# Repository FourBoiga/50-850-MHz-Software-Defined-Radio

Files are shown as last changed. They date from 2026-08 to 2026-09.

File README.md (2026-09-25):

# Wideband SDR (50–850 MHz)

## Overview

This project is a custom software-defined radio (SDR) designed to receive signals from approximately **50 MHz to 850 MHz**. The goal is to build a modular, low-cost SDR while learning RF engineering, analog design, FPGA development, and digital signal processing from the ground up.

Unlike many hobby SDRs that rely heavily on highly integrated tuner/transceiver ICs, this design uses discrete RF building blocks for much of the signal chain, including filtering, switching, amplification, mixing, local oscillator generation, and quadrature I/Q conversion.



---

## Goals

* Receive signals from approximately 50 MHz to 850 MHz
* Modular RF front-end
* Good dynamic range
* Low noise figure
* Quadrature I/Q output
* FPGA-based digital signal processing
* USB interface to a host PC
* Eventually interface with SDR software such as SDR++
* Learn professional RF and DSP design techniques

---

## Current Architecture

The signal starts at the antenna and passes through the RF protection and switched bandpass filter bank before being amplified by the LNA. From there it goes through the quadrature receiver and intermediate-frequency conversion stages, producing differential I/Q signals for the ADC. The ADC sends the digitized samples to the FPGA, where the DSP will be performed before the data is eventually sent to the host PC over USB.

---

The receiver uses multiple local oscillator paths generated from PLL frequency synthesizers referenced to a stable TCXO.

---

## Specifications

| Parameter | Specification |
| --- | ---: |
| Frequency Range | ~50–850 MHz |
| Architecture | Superheterodyne / Quadrature I/Q |
| Target IF Bandwidth | ~1 MHz |
| ADC | LTC2323-12 |
| ADC Resolution | 12-bit |
| ADC Sample Rate | 5 MSPS/channel |
| ADC Interface | SPI |
| FPGA | Sipeed Tang Nano 20K |
| Controller | STM32 Nucleo |
| Host Interface | USB |
| Output | Digital I/Q samples |

These are design targets and specifications; final RF performance will be determined through hardware testing and characterization.

---

## RF Front End

The RF front end consists of:

* RF input protection
* Switched bandpass filter bank
* RF switching
* Low-noise amplifier
* Quadrature receiver/mixer
* Intermediate-frequency conversion
* Local oscillator generation
* PLL frequency synthesizers
* TCXO reference

### Filter Architecture

The original design included additional filtering after the LNA. After reviewing the local RF environment and considering the additional simulation and design time required, the post-LNA filters were removed from the architecture.

The remaining pre-LNA filter bank provides the primary out-of-band filtering before amplification.

---

## Local Oscillator

The local oscillator system uses:

* Stable TCXO reference
* PLL frequency synthesizers
* LO generation for the receiver mixer
* LO generation for the IF mixer

The LO circuitry and synthesizers have been fully integrated into the PCB design.

---

## I/Q Receiver

The receiver produces differential I/Q signals which are digitized by the LTC2323-12 ADC.

During PCB design, the polarity of the Q differential pair was found to be opposite to the polarity expected by the ADC. Rather than rerouting the completed RF section, the differential inputs are intentionally swapped.

This produces a 180° phase inversion of the Q component, which will be corrected digitally in the FPGA by negating the Q samples.

---

## ADC

The SDR uses an **LTC2323-12** dual-channel 12-bit SAR ADC.

The planned configuration uses:

* 12-bit resolution
* 5 MSPS per channel
* Differential I/Q inputs
* SPI interface
* Up to 105 MHz SPI clock

The ADC provides the interface between the analog I/Q receiver and the FPGA's digital signal-processing chain.

---

## FPGA and DSP

The next major development phase is the FPGA firmware and digital signal processing.

The FPGA will initially implement a minimal processing chain capable of receiving and processing the raw I/Q samples from the ADC.

Planned processing includes:

```text
ADC I/Q Samples
       │
       ▼
Digital Filtering
       │
       ▼
Frequency Translation
       │
       ▼
Decimation
       │
       ▼
Sample Formatting
       │
       ▼
USB / Host PC
```

The FPGA development will be done using the **Sipeed Tang Nano 20K**.

The initial goal is not to immediately implement complete SDR++ compatibility. The first fallback target is simply to get raw or minimally processed I/Q samples from the FPGA to a computer.

A simple Python-based host program can then perform FFT processing and display the received spectrum. This provides a straightforward way to verify the complete RF → ADC → FPGA → PC signal path before implementing a more complete SDR software interface.

---

## PCB

The PCB design is now complete and is undergoing a final review before manufacturing.

Completed PCB work includes:

* RF protection
* Bandpass filter bank
* RF switching
* LNA
* Receiver/mixer circuitry
* Local oscillator circuitry
* PLL synthesizers
* I/Q differential routing
* ADC interface
* FPGA interface
* STM32 controller interface
* USB-C circuitry
* Debug SMA connector
* 50 Ω test line
* Test points
* Debug interfaces

The next steps are to perform the final PCB review, finalize the BOM, and submit the project for manufacturing/funding.

---

## Software

### FPGA

Planned FPGA functionality includes:

* LTC2323-12 SPI interface
* I/Q sample capture
* Q polarity correction
* Digital filtering
* Digital frequency translation
* Decimation
* I/Q data formatting
* USB data streaming

### Host PC

The initial host software will likely be a simple Python-based development tool capable of:

* Receiving I/Q samples
* Converting ADC samples into complex I/Q data
* Performing FFTs
* Displaying frequency spectra
* Visualizing received signals

The long-term goal is compatibility with existing SDR software such as SDR++.

---

## Major Engineering Challenges

* Wideband RF filter design
* RF PCB layout
* Maintaining controlled RF impedance
* Mixer integration
* Local oscillator synthesis
* LO phase noise
* Dynamic range
* Noise figure
* I/Q signal integrity
* ADC interfacing
* High-speed SPI
* FPGA DSP implementation
* Fixed-point digital signal processing
* Host-side I/Q streaming
* SDR software integration

One of the primary goals of the project is to understand and implement these individual systems rather than relying on a highly integrated SDR transceiver to hide their operation.

---

## Long-Term Goals

This project is intended to serve as a platform for experimentation and learning in:

* RF Engineering
* Analog Electronics
* RF PCB Design
* FPGA Development
* Digital Signal Processing
* Software-Defined Radio
* Communication Systems

Future revisions may improve filtering, dynamic range, instantaneous bandwidth, frequency coverage, DSP capabilities, and host software.

---

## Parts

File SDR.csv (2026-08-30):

Reference | Qty | Value | DNP | Exclude from BOM | Exclude from Board | Footprint | Datasheet | Description
C1,C2,C10,C11 | 4 | 100pF |  |  |  | Capacitor_SMD:C_0402_1005Metric |  | C0G
C3,C9,C58,C59,C60,C61,C62 | 7 | 10nF |  |  |  | Capacitor_SMD:C_0805_2012Metric |  | X7R
C4,C6 | 2 | 100nF |  |  |  | Capacitor_SMD:C_0603_1608Metric |  | Unpolarized capacitor, small symbol
C5,C14 | 2 | 33pF |  |  |  | Capacitor_SMD:C_0402_1005Metric |  | GJM1555C1H330FB01D
C7,C8 | 2 | 51pF |  |  |  | Capacitor_SMD:C_0402_1005Metric |  | CBR04C510F5GAC
C13,C15 | 2 | 5.6pF |  |  |  | Capacitor_SMD:C_0402_1005Metric |  | GJM1555C1H5R6BB01D
C16,C35 | 2 | 39pF |  |  |  | Capacitor_SMD:C_0402_1005Metric |  | GJM1555C1H390JB01D
C18 | 1 | 1.1pF |  |  |  | Capacitor_SMD:C_0402_1005Metric |  | GJM1555C1H1R1WB01D
C19,C20 | 2 | 16pF |  |  |  | Capacitor_SMD:C_0402_1005Metric |  | GJM1555C1H160FB01J
C24,C25,C26 | 3 | 12pF |  |  |  | Capacitor_SMD:C_0402_1005Metric |  | GJM1555C1H120FB01D
C27,C28,C29 | 3 | 100pF |  |  |  | Capacitor_SMD:C_0402_1005Metric |  | CBR04C101F3GAC
C30 | 1 | 1200pF |  |  |  | Capacitor_SMD:C_0402_1005Metric |  | GRM1555C1H122JA01D
C31 | 1 | 1uF |  |  |  | Capacitor_SMD:C_0603_1608Metric |  | GCM188R71E105KA64D
C63 | 1 | 10nF |  |  |  | Capacitor_SMD:C_0805_2012Metric |  | GRM2195C1H103JA01D
C64,C65,C66,C67,C86,C88,C101 | 7 | 1nF |  |  |  | Capacitor_SMD:C_0603_1608Metric |  | GRM1885C1H102JA01D
C70,C73,C74,C75,C76,C81,C100 | 7 | 100nF |  |  |  | Capacitor_SMD:C_0603_1608Metric |  | X7R
C71,C72,C122 | 3 | 100nF |  |  |  | Capacitor_SMD:C_0402_1005Metric |  | X7R
C77,C92,C95,C97,C102,C109,C110,C111,C112,C113,C120,C123,C125 | 13 | 1uF |  |  |  | Capacitor_SMD:C_0603_1608Metric |  | X7R
C78 | 1 | 2.7nF |  |  |  | Capacitor_SMD:C_0603_1608Metric |  | X7R
C79 | 1 | 47nF |  |  |  | Capacitor_SMD:C_0603_1608Metric |  | X7R
C80 | 1 | 680pF |  |  |  | Capacitor_SMD:C_0603_1608Metric |  | X7R
C82 | 1 | 3.9pF |  |  |  | Capacitor_SMD:C_0603_1608Metric |  | X7R
C83,C85 | 2 | 4.7pF |  |  |  | Capacitor_SMD:C_0603_1608Metric |  | X7R
C84 | 1 | 15pF |  |  |  | Capacitor_SMD:C_0603_1608Metric |  | X7R
C87 | 1 | 18pF |  |  |  | Capacitor_SMD:C_0603_1608Metric |  | X7R
C89,C103,C115,C116,C117,C118,C119 | 7 | 1nF |  |  |  | Capacitor_SMD:C_0603_1608Metric |  | X7R
C90,C91 | 2 | 220pF |  |  |  | Capacitor_SMD:C_0603_1608Metric |  | CC0603JRNPO9BN221
C93,C94,C96,C98 | 4 | 10uF |  |  |  | Capacitor_SMD:C_0805_2012Metric |  | X7R
C99 | 1 | 220nF |  |  |  | Capacitor_SMD:C_0603_1608Metric |  | X7R
C114,C121 | 2 | 10uF |  |  |  | Capacitor_SMD:C_0603_1608Metric |  | X7R
D1 | 1 | LED |  |  |  | LED_SMD:LED_0201_0603Metric |  | APT1608ZGCK
D2 | 1 | LED |  |  |  | LED_SMD:LED_0603_1608Metric |  | APT1608ZGCK
FB1,FB2 | 2 | FerriteBead |  |  |  | Inductor_SMD:L_0603_1608Metric |  | Ferrite bead
G1 | 1 | SIT8209AI-23-33E-180.000000 |  |  |  | Iguess:OSC_SiT8209AI-32-25E-133.300000 |  | 80 to 220 MHz, ±10 to ±50 ppm Oscillator
IC1,IC2 | 2 | RFSW6042TR7 |  |  |  | Iguess:QFN40P180X180X60-13N-D | https://www.qorvo.com/products/d/da001163 | 5 - 6000 MHz Low Insertion High Isolation SP4T Switch
IC5 | 1 | CMX992Q3 |  |  |  | Iguess:QFN50P700X700X100-49N-D | https://www.digikey.in/en/products/detail/cml-microcircuits/CMX992Q3/9989989 | RF Receiver High Performance 100MHz-1GHz RF Receiver
J1,J11,J12 | 3 | SMA |  |  |  | Connector_Coaxial:SMA_Amphenol_132289_EdgeMount |  | RF2-04A-T-00-50-G
J2,J13,J15 | 3 | Nucleo_GPIO |  |  |  | Connector_PinHeader_1.00mm:PinHeader_1x02_P1.00mm_Vertical |  | TS-101-G-AA
J3 | 1 | Nucleo_GPIO |  |  |  | Connector_PinHeader_1.00mm:PinHeader_1x03_P1.00mm_Vertical |  | TS-101-G-AA
J4 | 1 | Nucleo_GPIO |  |  |  | Connector_PinHeader_1.00mm:PinHeader_1x05_P1.00mm_Vertical |  | Generic connector, single row, 01x05, script generated
J5 | 1 | FPGA |  |  |  | Connector_Wire:SolderWire-0.25sqmm_1x02_P4.2mm_D0.65mm_OD1.7mm |  | Generic connector, single row, 01x02, script generated (kicad-library-utils/schlib/autogen/connector/)
J6,J7,J8 | 3 | Tang Nano |  |  |  | Connector_Wire:SolderWire-0.25sqmm_1x03_P4.5mm_D0.65mm_OD2mm |  | Generic connector, single row, 01x03, script generated
J9 | 1 | USB_C_Receptacle_PowerOnly_6P |  |  |  | Connector_USB:USB_C_Receptacle_GCT_USB4125-xx-x-0190_6P_TopMnt_Horizontal | https://www.usb.org/sites/default/files/documents/usb_type-c.zip | USB Power-Only 6P Type-C Receptacle connector
J14 | 1 | SMA |  |  |  | Connector_Coaxial:SMA_Amphenol_132291-12_Vertical |  | RF2-04A-T-00-50-G
L2 | 1 | 62nH |  |  |  | Inductor_SMD:L_0603_1608Metric |  | LQW18AN62NJ00D
L4,L5,L7,L9 | 4 | 39nH |  |  |  | Inductor_SMD:L_0603_1608Metric |  | LQW18AN39NJ00D
L8,L18 | 2 | 6.8nH |  |  |  | Inductor_SMD:L_0603_1608Metric |  | LQW18AN6N8C00D
L12 | 1 | 82nH |  |  |  | Inductor_SMD:L_0805_2012Metric |  | LQW2BAN82NJ00L
L13,L14,L20,L46 | 4 | 5.6nH |  |  |  | Inductor_SMD:L_0402_1005Metric |  | L06035R6CGSTR
L17,L19 | 2 | 4.3nH |  |  |  | Inductor_SMD:L_0402_1005Metric |  | LQW15AN4N3G80D
L21 | 1 | 68nH |  |  |  | Inductor_SMD:L_0603_1608Metric |  | LQW18AN68NG00D
L42 | 1 | 27nH |  |  |  | Inductor_SMD:L_0603_1608Metric |  | LQW18AN27NG10D
L43 | 1 | 33nH |  |  |  | Inductor_SMD:L_0603_1608Metric |  | LQW18AN33NJ00D
L44,L45 | 2 | 1μH |  |  |  | Inductor_SMD:L_0805_2012Metric |  | LQW2BAS1R0J00L
L47,L48 | 2 | 18nH |  |  |  | Inductor_SMD:L_0603_1608Metric |  | LQW18AN18NJ00D
R1,R3,R13,R14,R38,R46 | 6 | 1K |  |  |  | Resistor_SMD:R_0402_1005Metric |  | Resistor
R2,R4,R11,R12 | 4 | 2.2k |  |  |  | Resistor_SMD:R_0402_1005Metric |  | Resistor
R5,R6,R7,R8,R9,R10,R15 | 7 | 0 |  |  |  | Resistor_SMD:R_0402_1005Metric |  | Resistor
R29,R30 | 2 | 10 |  |  |  | Resistor_SMD:R_0402_1005Metric |  | Resistor
R31,R32,R33 | 3 | 3.3 |  |  |  | Resistor_SMD:R_0603_1608Metric |  | Resistor
R34,R53,R54 | 3 | 0 |  |  |  | Resistor_SMD:R_0603_1608Metric |  | Resistor
R35,R36 | 2 | DNP |  |  |  | Resistor_SMD:R_0603_1608Metric |  | Resistor
R37 | 1 | 5.1k |  |  |  | Resistor_SMD:R_0402_1005Metric |  | 1%+-
R39,R51 | 2 | 360 |  |  |  | Resistor_SMD:R_0603_1608Metric |  | Resistor
R40 | 1 | 220Ω |  |  |  | Resistor_SMD:R_0603_1608Metric |  | Resistor
R41 | 1 | 1200Ω |  |  |  | Resistor_SMD:R_0603_1608Metric |  | Resistor
R42,R43,R44,R45,R49 | 5 | 25 |  |  |  | Resistor_SMD:R_0805_2012Metric |  | Resistor
R47,R48 | 2 | 5.1K |  |  |  | Resistor_SMD:R_0402_1005Metric |  | Resistor
R50 | 1 | 360 |  |  |  | Resistor_SMD:R_0402_1005Metric |  | Resistor
TP1 | 1 | SCK- |  |  |  | TestPoint:TestPoint_Pad_D3.0mm |  | test point
TP2 | 1 | SCK+ |  |  |  | TestPoint:TestPoint_Pad_D3.0mm |  | test point
TP5,TP6,TP7,TP8,TP9 | 5 | TestPoint |  |  |  | TestPoint:TestPoint_Pad_D4.0mm |  | test point
TP10,TP11 | 2 | TestPoint |  |  |  | TestPoint:TestPoint_Pad_D2.0mm |  | test point
TR1 | 1 | TC1-1-13M+ |  |  |  | Iguess:AT224-1A
U1 | 1 | SGL0622Z |  |  |  | Package_DFN_QFN:DFN-8-1EP_2x2mm_P0.5mm_EP0.6x1.2mm | https://www.qorvo.com/products/d/da001879 | 5 MHz to 4000 MHz, Low-Noise SiGe HBT MMIC Amplifier, DFN-8
U2 | 1 | ADF4351BCPZ-RL7 |  |  |  | Package_CSP:LFCSP-32-1EP_5x5mm_P0.5mm_EP3.25x3.25mm | https://www.analog.com/media/en/technical-documentation/data-sheets/ADF4351.pdf | 35-4400MHz fractional-N PLL, LFCSP-32
U3 | 1 | ATX-H12-F-10.000MHZ-F25-T |  |  |  | Iguess:ATXH12F10000MHzF25T
U4 | 1 | MASWSS0115 |  |  |  | Package_TO_SOT_SMD:SOT-363_SC-70-6 | http://cdn.macom.com/datasheets/maswss0115.pdf | Macom GaAs RF SPDT switch, DC-3GHz, 0.3/22dB loss/isolation, SOT-363
U6 | 1 | LTC2323CUFD-12-PBF |  |  |  | Iguess:QFN-28_UFD_LIT | https://www.analog.com/media/en/technical-documentation/data-sheets/232312fb.pdf
U7 | 1 | LT1762-2.5 |  |  |  | Package_SO:MSOP-8_3x3mm_P0.65mm | https://www.analog.com/media/en/technical-documentation/data-sheets/LT1762.pdf | 2.5V, 150mA, Low Noise, Micropower LDO Regulator, MSOP-8
U8 | 1 | LT1962-3.3 |  |  |  | Package_SO:MSOP-8_3x3mm_P0.65mm | https://www.analog.com/media/en/technical-documentation/data-sheets/1962fb.pdf | 3.3V, 300mA, Low Noise, Micropower LDO Regulator, MSOP-8
U9,U10 | 2 | ECS-45K15B |  |  |  | Iguess:Untitled

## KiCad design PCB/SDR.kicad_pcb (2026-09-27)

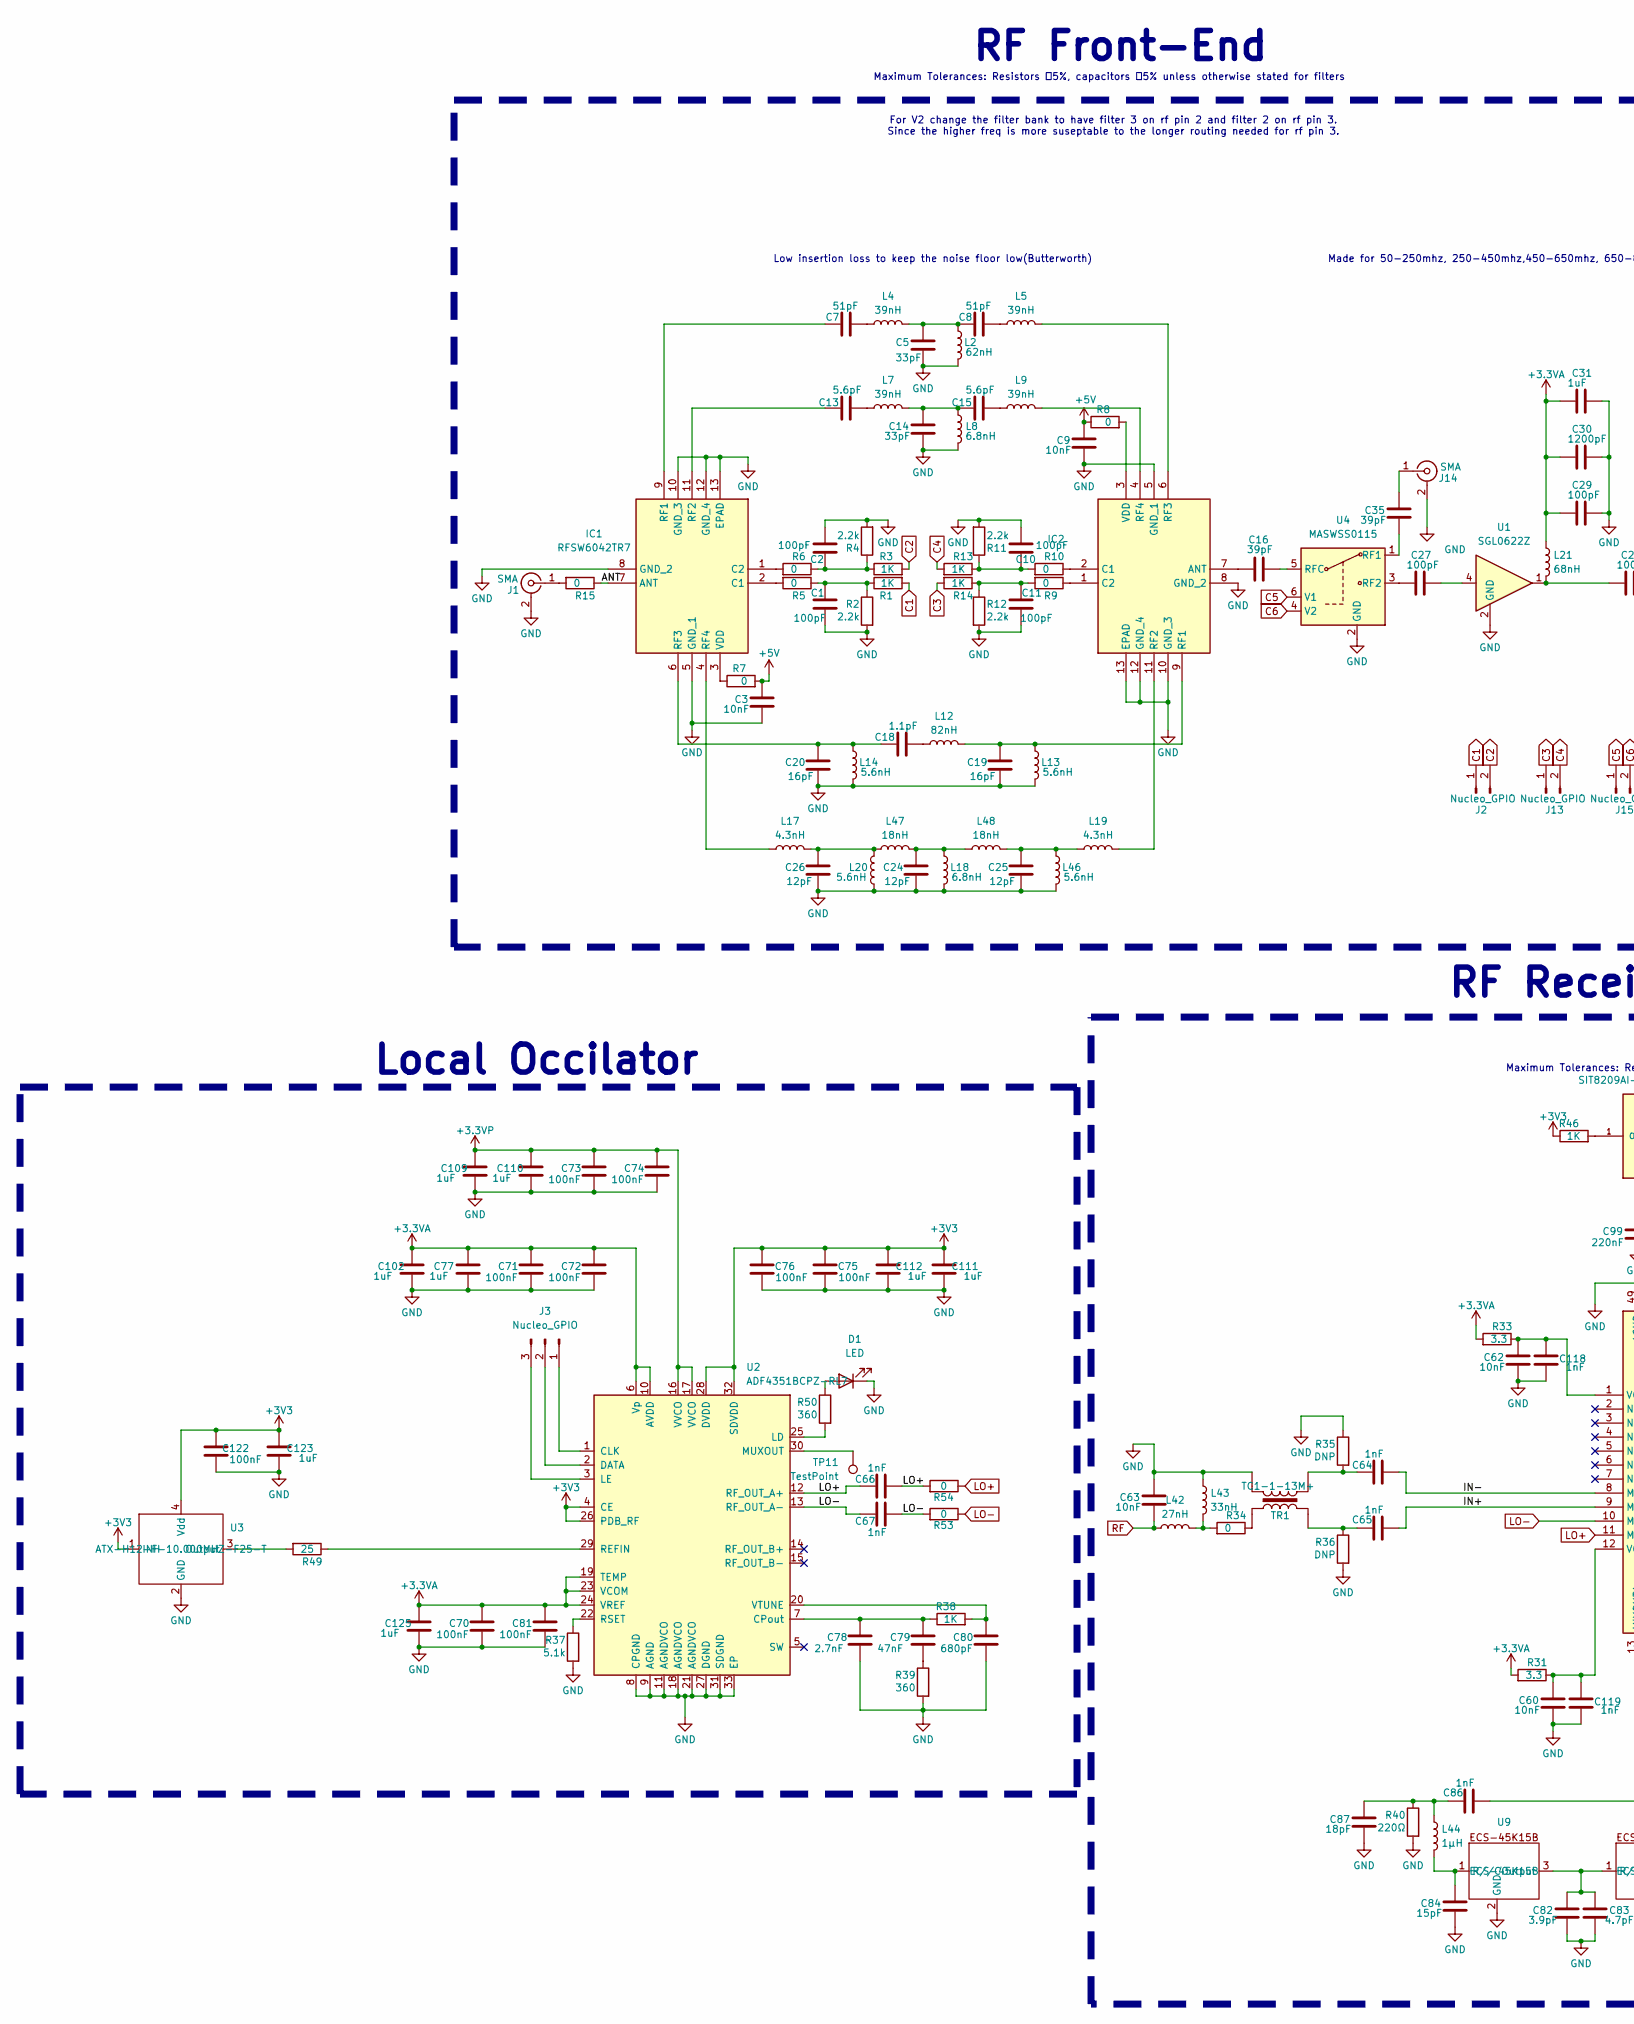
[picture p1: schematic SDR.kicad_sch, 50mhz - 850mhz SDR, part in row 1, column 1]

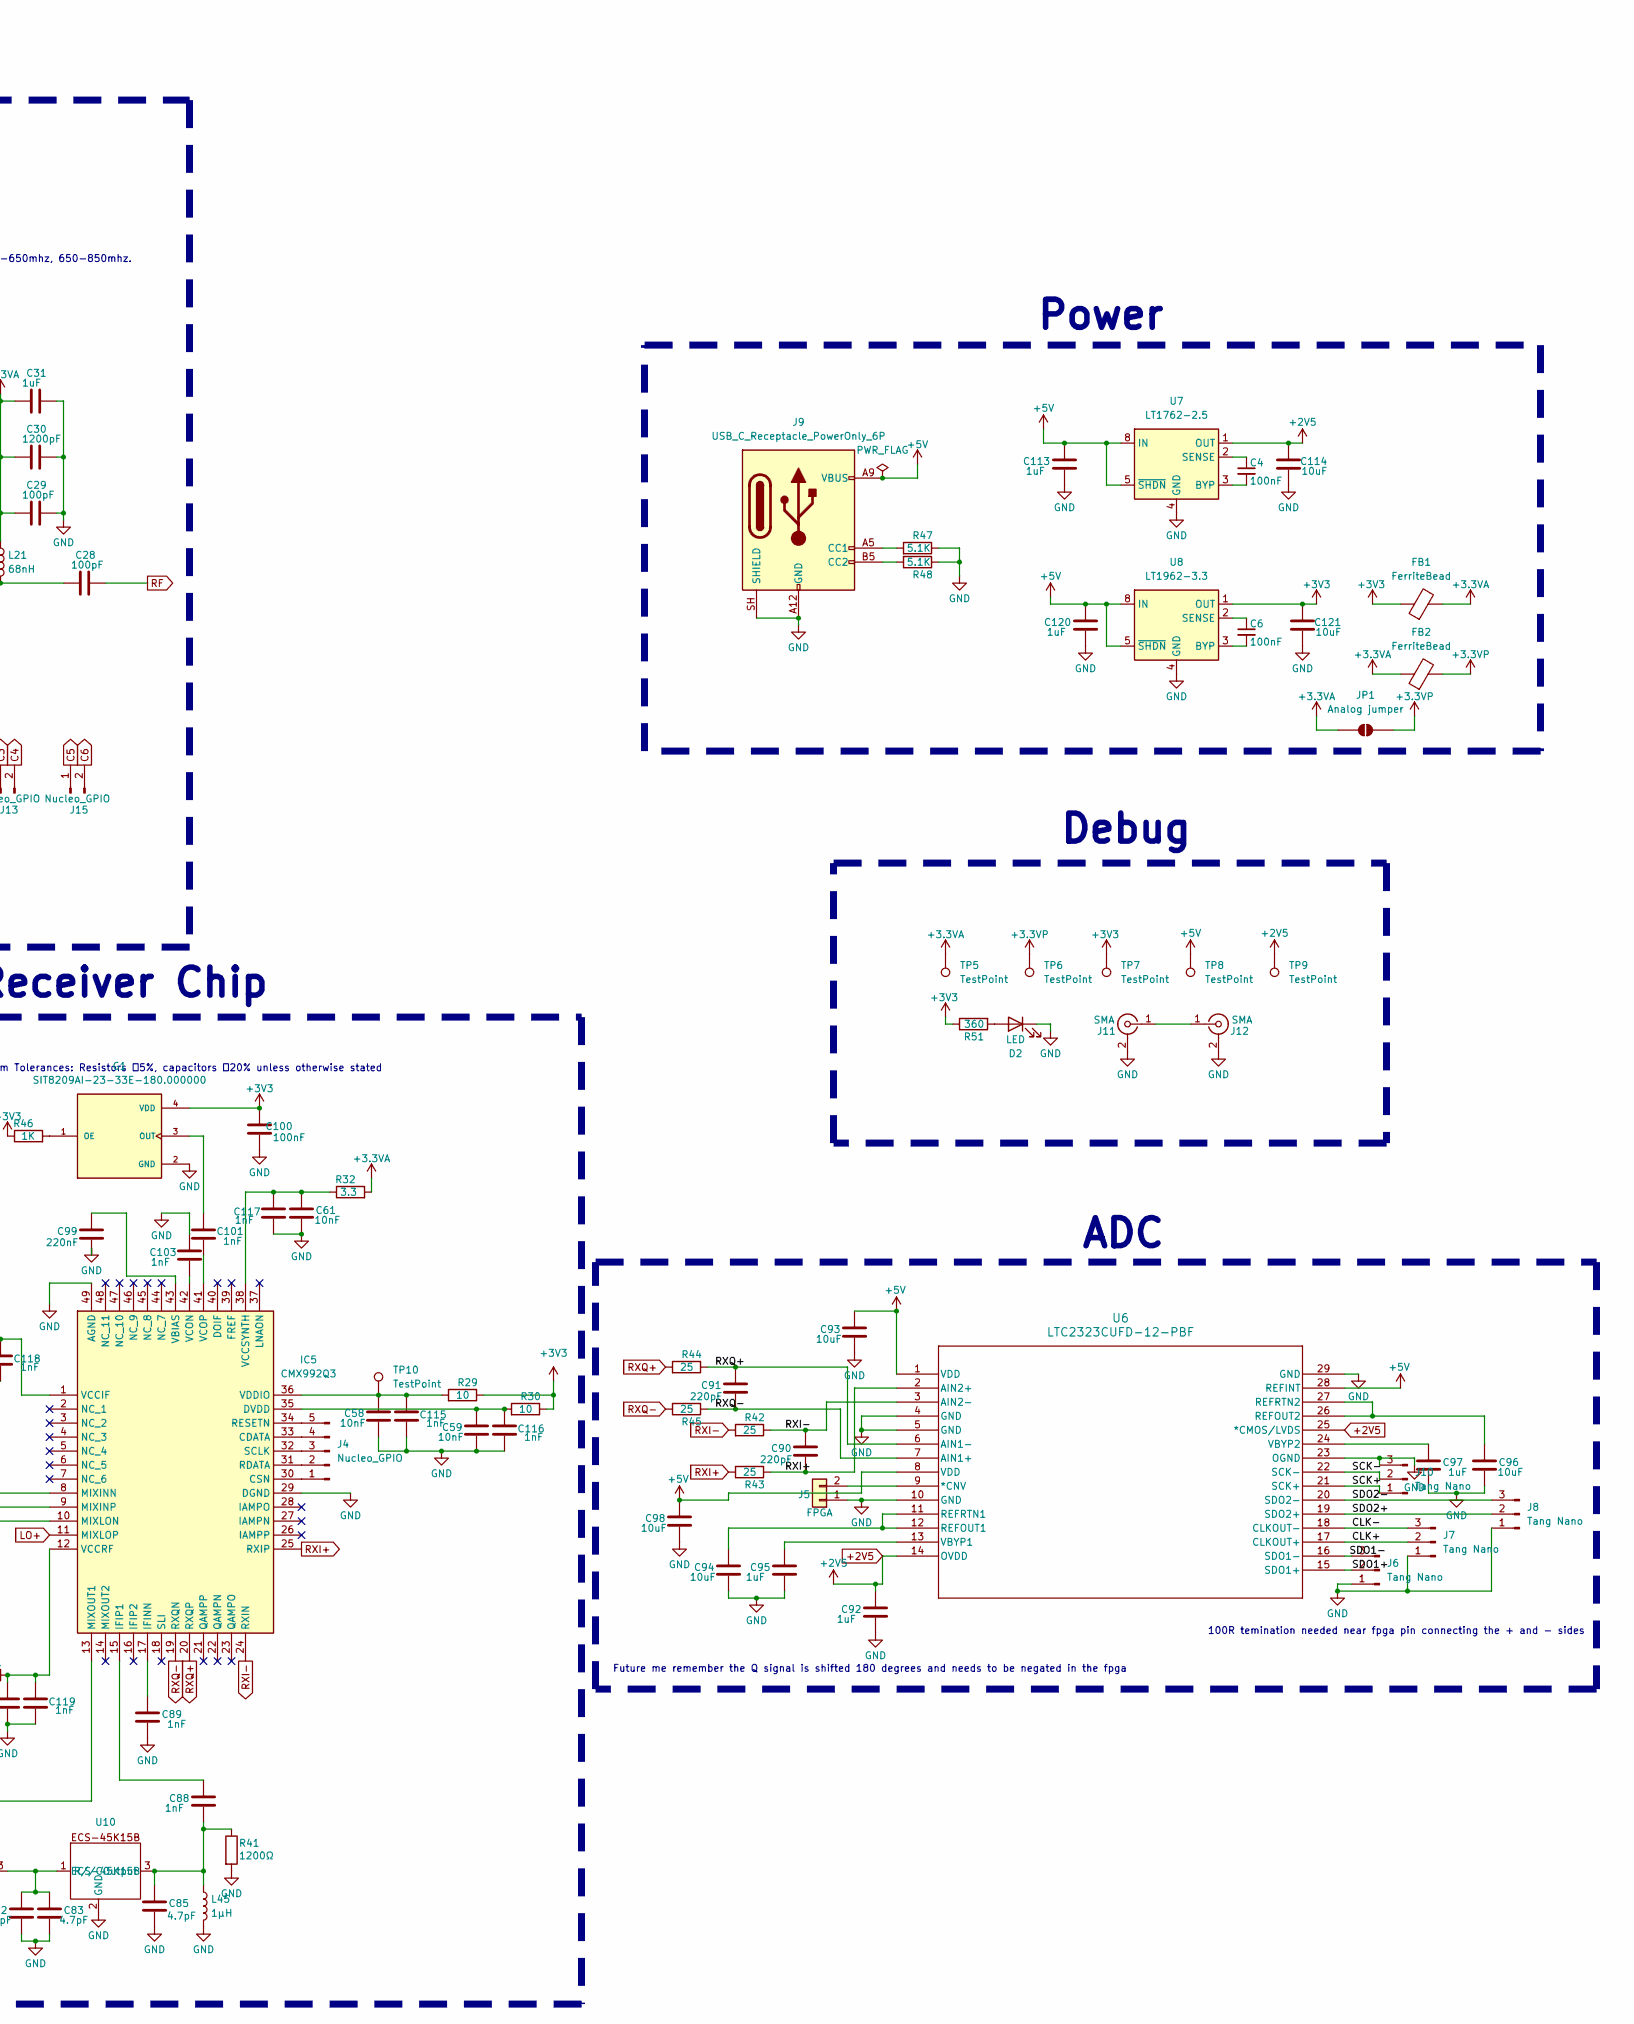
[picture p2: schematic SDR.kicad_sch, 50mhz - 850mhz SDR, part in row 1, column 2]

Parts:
C1, C2, C10, C11, C27, C28, C29: 100pF; C_0402_1005Metric
C3, C9, C58, C59, C60, C61, C62, C63: 10nF; C_0805_2012Metric
C4, C6, C70, C73, C74, C75, C76, C81, C100: 100nF; C_0603_1608Metric
C5, C14: 33pF; C_0402_1005Metric
C7, C8: 51pF; C_0402_1005Metric
C13, C15: 5.6pF; C_0402_1005Metric
C16, C35: 39pF; C_0402_1005Metric
C18: 1.1pF; C_0402_1005Metric
C19, C20: 16pF; C_0402_1005Metric
C24, C25, C26: 12pF; C_0402_1005Metric
C30: 1200pF; C_0402_1005Metric
C31, C77, C92, C95, C97, C102, C109, C110, C111, C112, C113, C120, C123, C125: 1uF; C_0603_1608Metric
C64, C65, C66, C67, C86, C88, C89, C101, C103, C115, C116, C117, C118, C119: 1nF; C_0603_1608Metric
C71, C72, C122: 100nF; C_0402_1005Metric
C78: 2.7nF; C_0603_1608Metric
C79: 47nF; C_0603_1608Metric
C80: 680pF; C_0603_1608Metric
C82: 3.9pF; C_0603_1608Metric
C83, C85: 4.7pF; C_0603_1608Metric
C84: 15pF; C_0603_1608Metric
C87: 18pF; C_0603_1608Metric
C90, C91: 220pF; C_0603_1608Metric
C93, C94, C96, C98: 10uF; C_0805_2012Metric
C99: 220nF; C_0603_1608Metric
C114, C121: 10uF; C_0603_1608Metric
D1, D2: LED; LED_0603_1608Metric
FB1, FB2: FerriteBead; L_0603_1608Metric
G1: SIT8209AI-23-33E-180.000000; OSC_SiT8209AI-32-25E-133.300000; PARTREV 1.1
IC1, IC2: RFSW6042TR7; QFN40P180X180X60-13N-D; Mouser Part Number 772-RFSW6042
IC5: CMX992Q3; QFN50P700X700X100-49N-D; Mouser Part Number 226-CMX992Q3
J1, J11, J12: SMA; SMA_Amphenol_132289_EdgeMount
J2, J13, J15: Nucleo_GPIO; PinHeader_1x02_P1.00mm_Vertical
J3: Nucleo_GPIO; PinHeader_1x03_P1.00mm_Vertical
J4: Nucleo_GPIO; PinHeader_1x05_P1.00mm_Vertical
J5: FPGA; SolderWire-0.25sqmm_1x02_P4.2mm_D0.65mm_OD1.7mm
J6, J7, J8, J10: Tang Nano; SolderWire-0.25sqmm_1x03_P4.5mm_D0.65mm_OD2mm
J9: USB_C_Receptacle_PowerOnly_6P; USB_C_Receptacle_GCT_USB4125-xx-x-0190_6P_TopMnt_Horizontal
J14: SMA; SMA_Amphenol_132291-12_Vertical
JP1: Analog jumper; SolderJumper-2_P1.3mm_Open_Pad1.0x1.5mm
L2: 62nH; L_0603_1608Metric
L4, L5, L7, L9: 39nH; L_0603_1608Metric
L8, L18: 6.8nH; L_0603_1608Metric
L12: 82nH; L_0805_2012Metric
L13, L14, L20, L46: 5.6nH; L_0402_1005Metric
L17, L19: 4.3nH; L_0402_1005Metric
L21: 68nH; L_0603_1608Metric
L42: 27nH; L_0603_1608Metric
L43: 33nH; L_0603_1608Metric
L44, L45: 1μH; L_0805_2012Metric
L47, L48: 18nH; L_0603_1608Metric
R1, R3, R13, R14, R38, R46: 1K; R_0402_1005Metric
R2, R4, R11, R12: 2.2k; R_0402_1005Metric
R5, R6, R7, R8, R9, R10, R15: 0; R_0402_1005Metric
R29, R30: 10; R_0402_1005Metric
R31, R32, R33: 3.3; R_0603_1608Metric
R34, R53, R54: 0; R_0603_1608Metric
R35, R36: DNP; R_0603_1608Metric
R37: 5.1k; R_0402_1005Metric
R39, R51: 360; R_0603_1608Metric
R40: 220Ω; R_0603_1608Metric
R41: 1200Ω; R_0603_1608Metric
R42, R43, R44, R45, R49: 25; R_0805_2012Metric
R47, R48: 5.1K; R_0402_1005Metric
R50: 360; R_0402_1005Metric
TP5, TP6, TP7, TP8, TP9: TestPoint; TestPoint_Pad_D4.0mm
TP10, TP11: TestPoint; TestPoint_Pad_D2.0mm
TR1: TC1-1-13M+; AT224-1A
U1: SGL0622Z; DFN-8-1EP_2x2mm_P0.5mm_EP0.6x1.2mm
U2: ADF4351BCPZ-RL7; LFCSP-32-1EP_5x5mm_P0.5mm_EP3.25x3.25mm
U3: ATX-H12-F-10.000MHZ-F25-T; ATXH12F10000MHzF25T
U4: MASWSS0115; SOT-363_SC-70-6
U6: LTC2323CUFD-12-PBF; QFN-28_UFD_LIT
U7: LT1762-2.5; MSOP-8_3x3mm_P0.65mm
U8: LT1962-3.3; MSOP-8_3x3mm_P0.65mm
U9, U10: ECS-45K15B; Untitled

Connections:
+2V5: C92.1, C114.1, TP9.1 (1_1), U6.14 (OVDD), U6.25 (*CMOS/LVDS), U7.1 (OUT)
+3.3VA: C29.2, C30.2, C31.2, C70.1, C71.1, C72.1, C77.1, C81.1, C102.1, C125.1, FB1.2, FB2.1, JP1.1 (A), L21.1, R31.2, R32.2, R33.2, TP5.1 (1_1), U2.6 (Vp), U2.10 (AVDD), U2.19 (TEMP), U2.23 (VCOM), U2.24 (VREF)
+3.3VP: C73.1, C74.1, C109.1, C110.1, FB2.2, JP1.2 (B), TP6.1 (1_1), U2.16 (VVCO), U2.17 (VVCO)
+3V3: C75.1, C76.1, C100.1, C111.1, C112.1, C121.1, C122.1, C123.1, FB1.1, G1.4 (VDD), R29.1, R30.1, R46.1, R51.1, TP7.1 (1_1), U2.4 (CE), U2.26 (PDB_RF), U2.28 (DVDD), U2.32 (SDVDD), U3.1 (INH), U3.4 (Vdd), U8.1 (OUT)
+5V: C3.1, C9.1, C93.1, C98.1, C113.1, C120.1, J9.A9 (VBUS), J9.B9 (VBUS), R7.2, R8.1, TP8.1 (1_1), U6.1 (VDD), U6.8 (VDD), U6.28 (REFINT), U7.5 (~SHDN), U7.8 (IN), U8.5 (~SHDN), U8.8 (IN)
/ANT: IC1.7 (ANT), R15.1
/CLK+: J7.2, U6.17 (CLKOUT+)
/CLK-: J7.3, U6.18 (CLKOUT-)
/IN+: C65.1, IC5.9 (MIXINP)
/IN-: C64.1, IC5.8 (MIXINN)
/SCK+: J10.1, U6.21 (SCK+)
/SCK-: J10.2, U6.22 (SCK-)
/SDO1+: J6.2, U6.15 (SDO1+)
/SDO1-: J6.3, U6.16 (SDO1-)
/SDO2+: J8.2, U6.19 (SDO2+)
/SDO2-: J8.3, U6.20 (SDO2-)
C1: J2.1, R1.2
C2: J2.2, R3.2
C3: J13.1, R14.2
C4: J13.2, R13.2
C5: J15.1, U4.6 (V1)
C6: J15.2, U4.4 (V2)
GND: C1.2, C2.2, C3.2, C5.2, C9.2, C10.2, C11.2, C14.2, C19.2, C20.2, C24.2, C25.2, C26.2, C29.1, C30.1, C31.1, C58.2, C59.2, C60.2, C61.2, C62.2, C63.1, C70.2, C71.2, C72.2, C73.2, C74.2, C75.2, C76.2, C77.2, C78.2, C80.2, C81.2, C82.2, C83.2, C84.2, C85.2, C87.2, C89.2, C92.2, C93.2, C94.2, C95.2, C96.2, C97.2, C98.2, C99.2, C100.2, C102.2, C103.1, C109.2, C110.2, C111.2, C112.2, C113.2, C114.2, C115.2, C116.2, C117.2, C118.2, C119.2, C120.2, C121.2, C122.2, C123.2, C125.2, D1.1 (K), D2.1 (K), G1.2 (GND), IC1.5 (GND_1), IC1.8 (GND_2), IC1.10 (GND_3), IC1.12 (GND_4), IC1.13 (EPAD), IC2.5 (GND_1), IC2.8 (GND_2), IC2.10 (GND_3), IC2.12 (GND_4), IC2.13 (EPAD), IC5.29 (DGND), IC5.49 (AGND), J1.2 (Ext), J5.1, J6.1, J7.1, J8.1, J9.A12 (GND), J9.B12 (GND), J9.SH (SHIELD), J10.3, J11.2 (Ext), J12.2 (Ext), J14.2 (Ext), L2.2, L8.2, L13.2, L14.2, L18.2, L20.2, L43.1, L45.2, L46.2, R2.2, R4.2, R11.2, R12.2, R35.1, R36.2, R37.2, R39.2, R40.2, R41.2, R47.1, R48.1, TR1.6, U1.2 (GND), U1.3 (GND), U1.5 (GND), U1.6 (GND), U1.7 (GND), U1.8 (GND), U1.9 (GND), U2.8 (CPGND), U2.9 (AGND), U2.11 (AGNDVCO), U2.18 (AGNDVCO), U2.21 (AGNDVCO), U2.27 (DGND), U2.31 (SDGND), U2.33 (EP), U3.2 (GND), U4.2 (GND), U6.4 (GND), U6.5 (GND), U6.10 (GND), U6.23 (OGND), U6.29 (GND), U7.4 (GND), U8.4 (GND), U9.2 (GND), U10.2 (GND)
LO+: C66.1, C66.2, IC5.11 (MIXLOP), R54.1, R54.2, U2.12 (RF_OUT_A+)
LO-: C67.1, C67.2, IC5.10 (MIXLON), R53.1, R53.2, U2.13 (RF_OUT_A-)
unnamed: C1.1, R1.1, R2.1, R5.1
unnamed: C2.1, R3.1, R4.1, R6.1
unnamed: C5.1, C8.2, L2.1, L4.2
unnamed: C7.1, L4.1
unnamed: C8.1, L5.1
unnamed: C10.1, R10.2, R11.1, R13.1
unnamed: C11.1, R9.2, R12.1, R14.1
unnamed: C13.1, L7.1
unnamed: C14.1, C15.2, L7.2, L8.1
unnamed: C15.1, L9.1
unnamed: C18.1, L12.1
unnamed: C24.1, L18.1, L47.2, L48.1
unnamed: C25.1, L19.1, L46.1, L48.2
unnamed: C26.1, L17.2, L20.1, L47.1
unnamed: C27.1, U1.4
unnamed: C28.2, L21.2, U1.1
unnamed: C64.2, R35.2, TR1.1
unnamed: C65.2, R36.1, TR1.3
unnamed: C79.2, R39.1
unnamed: C86.2, C87.1, L44.1, R40.1
unnamed: D1.2 (A), R50.1
unnamed: D2.2 (A), R51.2
unnamed: G1.1 (OE), R46.2
unnamed: C101.1, G1.3 (OUT)
unnamed: IC1.2 (C1), R5.2
unnamed: IC1.1 (C2), R6.2
unnamed: C7.2, IC1.9 (RF1)
unnamed: C13.2, IC1.11 (RF2)
unnamed: C18.2, C20.1, IC1.6 (RF3), L14.1
unnamed: IC1.4 (RF4), L17.1
unnamed: IC1.3 (VDD), R7.1
unnamed: C16.2, IC2.7 (ANT)
unnamed: IC2.2 (C1), R10.1
unnamed: IC2.1 (C2), R9.1
unnamed: C19.1, IC2.9 (RF1), L12.2, L13.1
unnamed: IC2.11 (RF2), L19.2
unnamed: IC2.6 (RF3), L5.2
unnamed: IC2.4 (RF4), L9.2
unnamed: IC2.3 (VDD), R8.2
unnamed: IC5.33 (CDATA), J4.4
unnamed: IC5.30 (CSN), J4.1
unnamed: C59.1, C116.1, IC5.35 (DVDD), R30.2
unnamed: C89.1, IC5.17 (IFINN)
unnamed: C88.1, IC5.15 (IFIP1)
unnamed: C86.1, IC5.13 (MIXOUT1)
unnamed: IC5.31 (RDATA), J4.2
unnamed: IC5.34 (RESETN), J4.5
unnamed: IC5.32 (SCLK), J4.3
unnamed: C99.1, IC5.43 (VBIAS)
unnamed: C62.1, C118.1, IC5.1 (VCCIF), R33.1
unnamed: C60.1, C119.1, IC5.12 (VCCRF), R31.1
unnamed: C61.1, C117.1, IC5.38 (VCCSYNTH), R32.1
unnamed: C103.2, IC5.42 (VCON)
unnamed: C101.2, IC5.41 (VCOP)
unnamed: C58.1, C115.1, IC5.36 (VDDIO), R29.2, TP10.1 (1_1)
unnamed: J1.1 (In), R15.2
unnamed: J3.1, U2.1 (CLK)
unnamed: J3.2, U2.2 (DATA)
unnamed: J3.3, U2.3 (LE)
unnamed: J5.2, U6.9 (*CNV)
unnamed: J9.A5 (CC1), R47.2
unnamed: J9.B5 (CC2), R48.2
unnamed: J11.1 (In), J12.1 (In)
unnamed: C35.1, J14.1 (In)
unnamed: L42.2, L43.2, R34.2
unnamed: R34.1, TR1.4
unnamed: C78.1, C79.1, R38.1, U2.7 (CPout)
unnamed: R50.2, U2.25 (LD)
unnamed: TP11.1 (1_1), U2.30 (MUXOUT)
unnamed: R49.1, U2.29 (REFIN)
unnamed: R37.1, U2.22 (RSET)
unnamed: C80.1, R38.2, U2.20 (VTUNE)
unnamed: R49.2, U3.3 (Output)
unnamed: C35.2, U4.1 (RF1)
unnamed: C27.2, U4.3 (RF2)
unnamed: C16.1, U4.5 (RFC)
unnamed: C94.1, U6.11 (REFRTN1), U6.12 (REFOUT1)
unnamed: C96.1, U6.26 (REFOUT2), U6.27 (REFRTN2)
unnamed: C95.1, U6.13 (VBYP1)
unnamed: C97.1, U6.24 (VBYP2)
unnamed: C4.2, U7.3 (BYP)
unnamed: C4.1, U7.2 (SENSE)
unnamed: C6.2, U8.3 (BYP)
unnamed: C6.1, U8.2 (SENSE)
unnamed: C84.1, L44.2, U9.1 (R//C)
unnamed: C85.1, C88.2, L45.1, R41.1, U10.3 (Output)
unnamed: C82.1, C83.1, U9.3 (Output), U10.1 (R//C)
RF: C28.1, C63.2, L42.1
RXI+: C90.2, IC5.25 (RXIP), R43.1, R43.2, U6.2 (AIN2+)
RXI-: C90.1, IC5.24 (RXIN), R42.1, R42.2, U6.3 (AIN2-)
RXQ+: C91.1, IC5.20 (RXQP), R44.1, R44.2, U6.6 (AIN1-)
RXQ-: C91.2, IC5.19 (RXQN), R45.1, R45.2, U6.7 (AIN1+)

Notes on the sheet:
100R temination needed near fpga pin connecting the + and - sides
Future me remember the Q signal is shifted 180 degrees and needs to be negated in the fpga
Low insertion loss to keep the noise floor low(Butterworth)
RF Front-End
Debug
Maximum Tolerances: Resistors 5%, capacitors 5% unless otherwise stated for filters
For V2 change the filter bank to have filter 3 on rf pin 2 and filter 2 on rf pin 3. Since the higher freq is more suseptable to the longer routing needed for rf pin 3.
Maximum Tolerances: Resistors 5%, capacitors 20% unless otherwise stated
Power
Made for 50-250mhz, 250-450mhz,450-650mhz, 650-850mhz.
ADC
Local Occilator
RF Receiver Chip

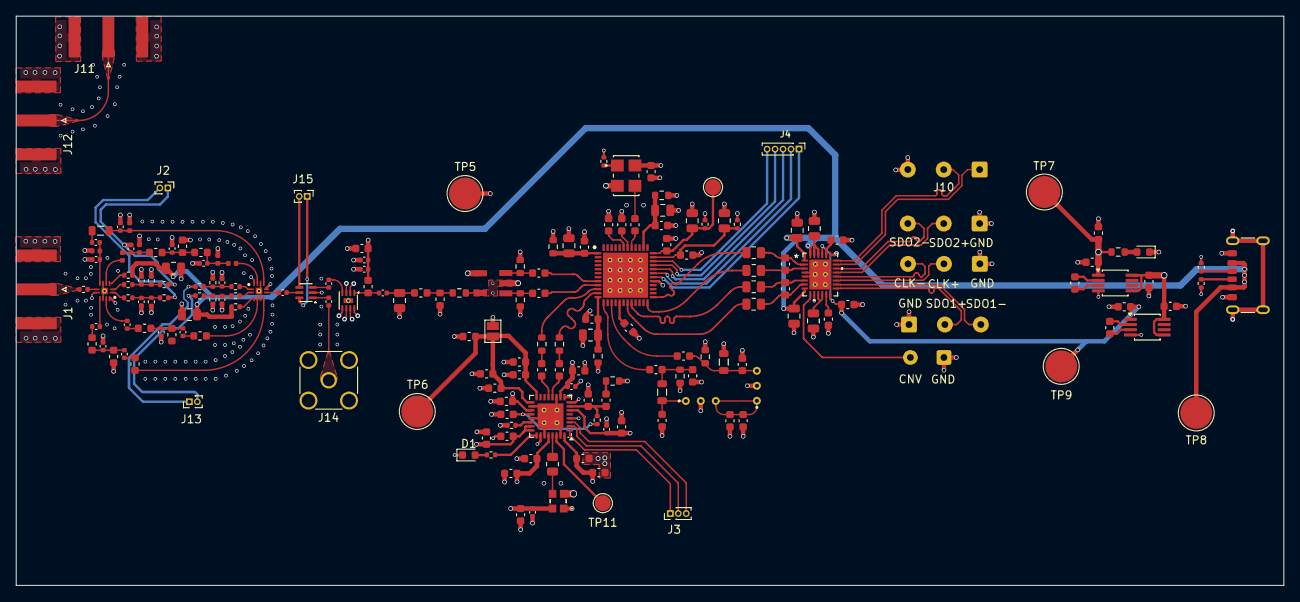
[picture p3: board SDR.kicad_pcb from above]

Board: 4 copper layers, 158.8 x 71.3 mm, 189 parts (0 on the bottom side), 117 nets.
